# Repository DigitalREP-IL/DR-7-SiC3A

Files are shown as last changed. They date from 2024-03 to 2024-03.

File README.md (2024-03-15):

The Raspberry Pi, while a very capable and useful single-board computer, is often used with less than ideal power supplies. The Raspberry Pi monitors the incoming power and can both warn the user and slow down the system (clock throttling) to reduce power consumption. It is very common to have issues with SD Card corruption that can be traced back to power input issues as well. The simple solution presented by many kit vendors is to supply a power supply that provides 5.1V rather than the 5.0V nominal, in hopes that the extra voltage compensates for resistive losses in the cabling and by providing additional headroom over the 4.63V undervoltage warning level. However, a large contingent of would-be makers simply use a cellular phone charger and hope for the best. On older models, the power draw was somewhat lower but as of the latest 3B and 4 models the recommended supply current has risen to 3A.  Additionally, most USB chargers perform poorly at higher loads and may even drop out, hiccupping power to the SBC.

With this in mind, we’ve designed a DC/DC converter using the Vishay SiC-468 that can use common higher voltage power supplies such as a laptop “brick”, converting a 10-28V supply voltage to a very dependable 5V/3A output. The efficiency is typically above 92%, which is not only good for the environment but also keeps heat buildup to a minimum.

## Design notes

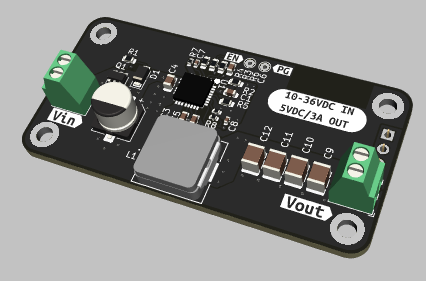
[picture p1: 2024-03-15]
DR-7-SiC3A glamour shot.PNG

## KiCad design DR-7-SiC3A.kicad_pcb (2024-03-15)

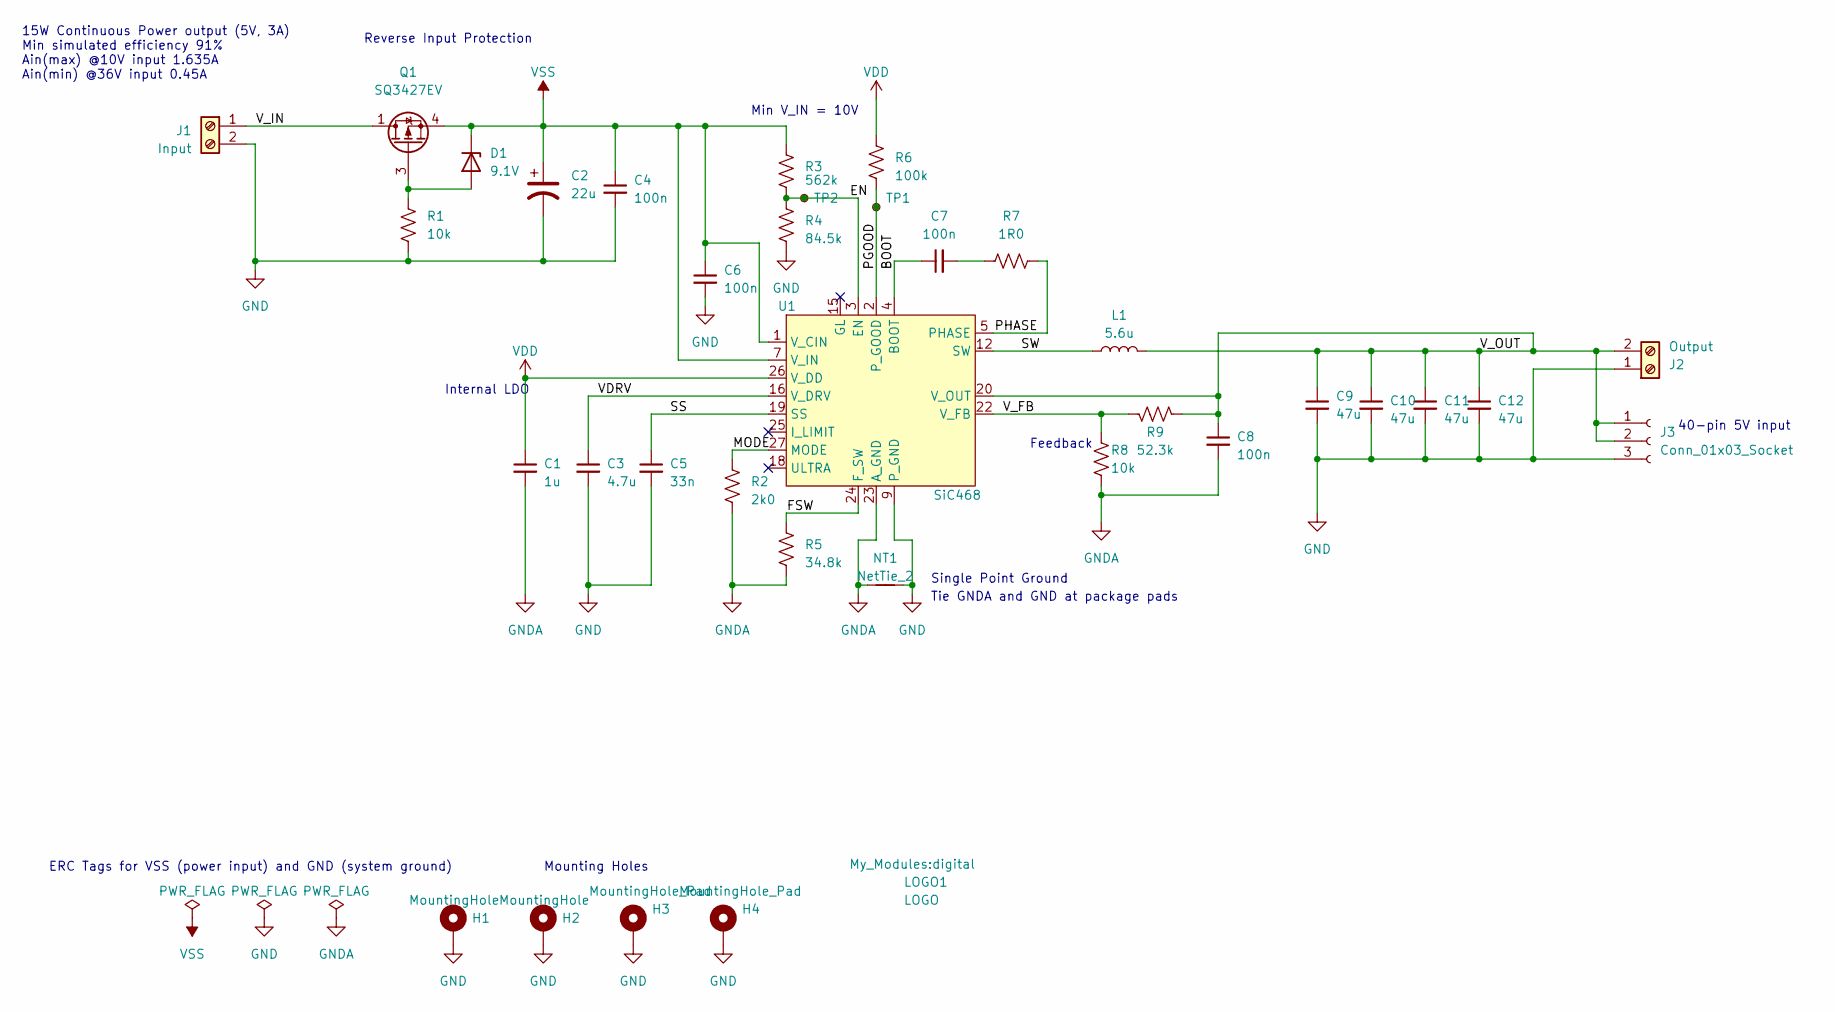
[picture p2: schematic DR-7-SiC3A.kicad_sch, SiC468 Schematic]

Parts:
C1: 1u; C_0603_1608Metric
C2: 22u; CP_Elec_6.3x5.8
C3: 4.7u; C_0603_1608Metric
C4: 100n; C_0805_2012Metric
C5: 33n; C_0603_1608Metric
C6: 100n; C_0603_1608Metric
C7, C8: 100n; C_0402_1005Metric
C9, C10, C11, C12: 47u; C_1210_3225Metric
D1: 9.1V; D_SMF; MPN BZG05C9V1-M3-08
H1, H2: MountingHole; MountingHole_2.7mm_M2.5_DIN965_Pad_TopBottom
H3, H4: MountingHole_Pad; MountingHole_2.7mm_M2.5_DIN965_Pad_TopBottom
J1: Input; TerminalBlock_Phoenix_MPT-0,5-2-2.54_1x02_P2.54mm_Horizontal
J2: Output; TerminalBlock_Phoenix_MPT-0,5-2-2.54_1x02_P2.54mm_Horizontal
J3: Conn_01x03_Socket; PinSocket_1x03_P2.54mm_Vertical
L1: 5.6u; IND_IHLP-4040DZ_VIS; MPN IHLP4040DZER5R6M01
LOGO1: LOGO; digital
NT1: NetTie_2; NetTie-2_SMD_Pad0.5mm
Q1: SQ3427EV; TSOP-6_1.65x3.05mm_P0.95mm; MPN SQ3427EV-T1_GE3
R1: 10k; R_0603_1608Metric
R2: 2k0; R_0603_1608Metric
R3: 562k; R_0603_1608Metric
R4: 84.5k; R_0603_1608Metric
R5: 34.8k; R_0603_1608Metric
R6: 100k; R_0603_1608Metric
R7: 1R0; R_0402_1005Metric
R8: 10k; R_0402_1005Metric
R9: 52.3k; R_0402_1005Metric
TP1, TP2: TestPoint_Small; TestPoint_THTPad_D1.5mm_Drill0.7mm
U1: SiC468; MLP55-27L; MPN SIC468ED-T1-GE3

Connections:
/BOOT: C7.1, U1.4 (BOOT)
/EN: R3.1, R4.2, TP2.1, U1.3 (EN)
/FSW: R5.2, U1.24 (F_SW)
/MODE: R2.2, U1.27 (MODE)
/PGOOD: R6.1, TP1.1, U1.2 (P_GOOD)
/PHASE: R7.2, U1.5 (PHASE), U1.6 (PHASE)
/SS: C5.1, U1.19 (SS)
/SW: L1.1, U1.12 (SW), U1.13 (SW), U1.14 (SW)
/VDRV: C3.1, U1.16 (V_DRV)
/V_FB: R8.2, R9.1, U1.22 (V_FB)
/V_IN: J1.1, Q1.1 (D), Q1.2 (D), Q1.5 (D), Q1.6 (D)
/V_OUT: C8.1, C9.1, C10.1, C11.1, C12.1, J2.2, J3.1, J3.2, L1.2, R9.2, U1.20 (V_OUT)
GND: C2.2, C3.2, C4.2, C5.2, C6.2, C9.2, C10.2, C11.2, C12.2, H1.1, H2.1, H3.1, H4.1, J1.2, J2.1, J3.3, NT1.2, R1.1, R4.1, U1.9 (P_GND), U1.10 (P_GND), U1.11 (P_GND), U1.17 (P_GND), U1.30 (P_GND)
GNDA: C1.2, C8.2, NT1.1, R2.1, R5.1, R8.1, U1.23 (A_GND), U1.28 (A_GND)
unnamed: C7.2, R7.1
unnamed: D1.2 (A), Q1.3 (G), R1.2
VDD: C1.1, R6.2, U1.26 (V_DD)
VSS: C2.1, C4.1, C6.1, D1.1 (K), Q1.4 (S), R3.2, U1.1 (V_CIN), U1.7 (V_IN), U1.8 (V_IN), U1.29 (V_IN)

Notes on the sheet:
Internal LDO
ERC Tags for VSS (power input) and GND (system ground)
Reverse Input Protection
Feedback
Single Point Ground
Tie GNDA and GND at package pads
15W Continuous Power output (5V, 3A) Min simulated efficiency 91% Ain(max) @10V input 1.635A Ain(min) @36V input 0.45A
Min V_IN = 10V
Mounting Holes
40-pin 5V input

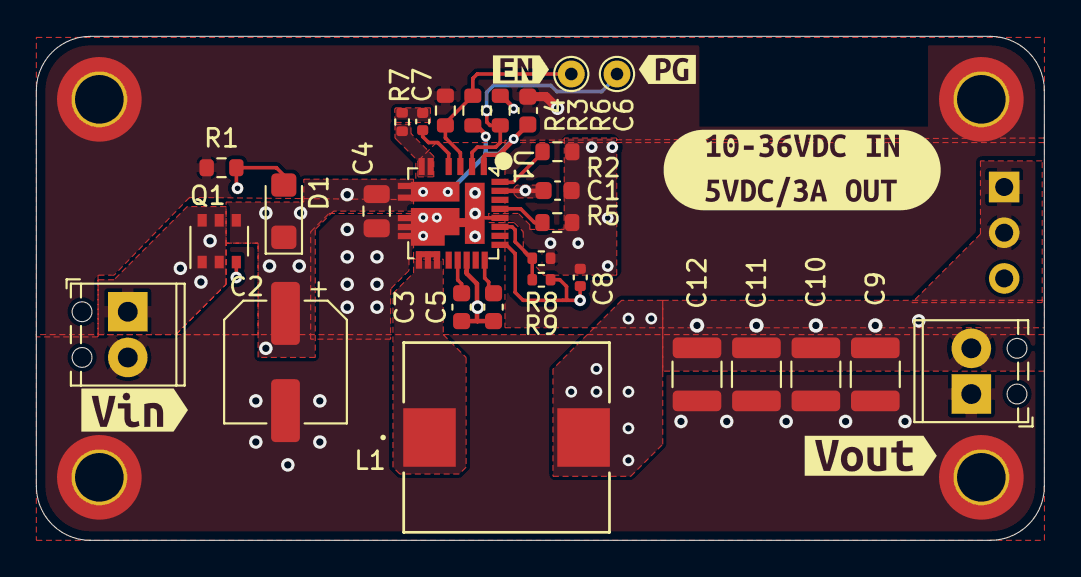
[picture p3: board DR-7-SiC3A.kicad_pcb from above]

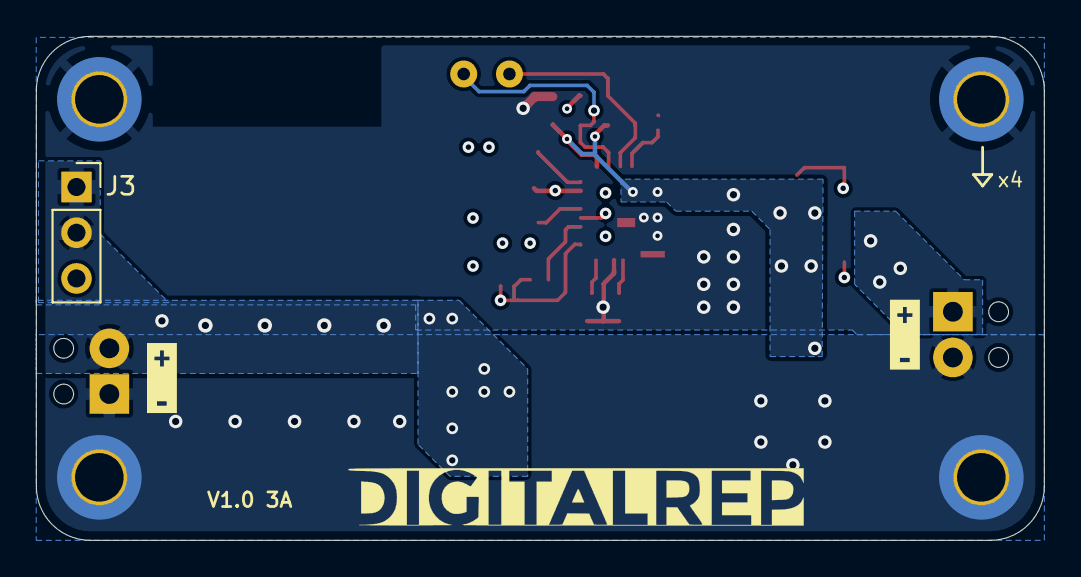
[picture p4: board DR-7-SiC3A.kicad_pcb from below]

Board: 4 copper layers, 56.0 x 28.0 mm, 43 parts (4 on the bottom side), 18 nets.

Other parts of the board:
kibuzzard-64C2B50E: G***; kibuzzard-64C2B50E
kibuzzard-64C2B51C: G***; kibuzzard-64C2B51C
kibuzzard-64C2B535: G***; kibuzzard-64C2B535
kibuzzard-64C2B591: G***; kibuzzard-64C2B591
kibuzzard-64469095, kibuzzard-64469095#2: G***; kibuzzard-64469095
kibuzzard-65242275: G***; kibuzzard-65242275
